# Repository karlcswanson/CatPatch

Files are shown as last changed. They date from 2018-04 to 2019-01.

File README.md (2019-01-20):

# CatPatch
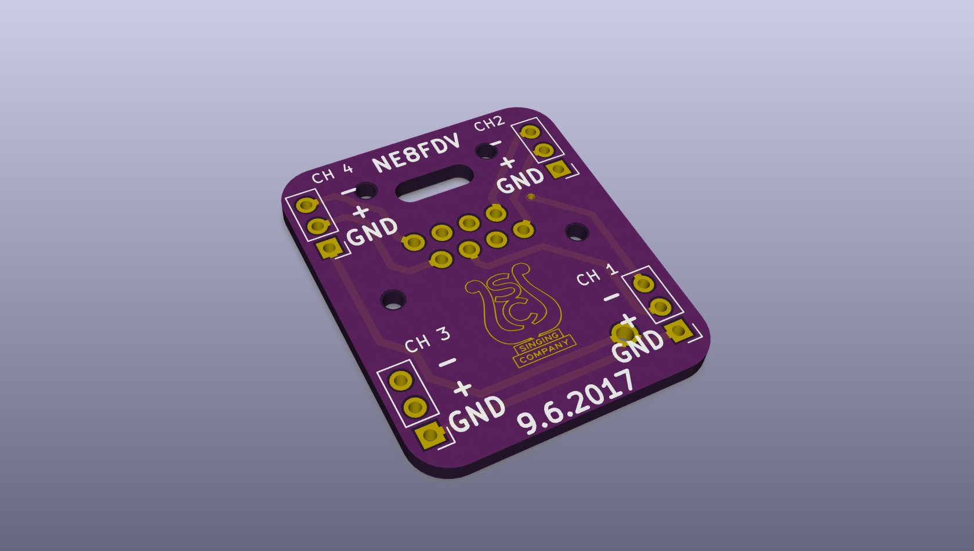
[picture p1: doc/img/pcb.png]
PCB


This repository contains images and KiCad files for a CAT5e subsnake and DI system.

A brief build log for the DI and breakout cable can be found [here](https://imgur.com/a/OviKR).

## Pinouts
The system, as labeled, is pin-compatible with RAT and ETS audio twisted pair products.  The silkscreen and wiring can be adjusted to make it compatible with other standards.

| RJ45 Pin | [T568B](https://en.wikipedia.org/wiki/TIA/EIA-568#Wiring) | RAT & ETS | Radial & Whirlwind |
|:---:|:---:|:---:|:---:|
| 1 | WO | 2+ | 1+ |
| 2 | O | 2- | 1- |
| 3 | WG | 3+ | 2+ |
| 4 | B | 1- | 3+ |
| 5 | WB | 1+ | 3- |
| 6 | G | 3- | 2- |
| 7 | WBr | 4+ | 4+ |
| 8 | Br | 4- | 4- |
---
###### Sources
[RAT CAT Snake](http://www.ratsoundsales.com/mm5/pdf/etherCON_wiring_diagram.pdf) | [Radial Catapult](http://www.radialeng.com/wp-content/uploads/2018/05/Catapult-userguide.pdf) | [Whirlwind Catdusa](http://whirlwindusa.com/media/uploads/catdusa_manual.pdf)

## Cable
Shielded cable is needed when using phantom powered, Clear-Com, and DMX devices over twisted pair.  These devices require pin 1/ground to work. An EtherCON connector does not indicate that a cable is shielded.

Dynamic mics and passive DIs may work without the recommended shield.

## DI
The DI PCB supports the Jensen JT-DB-EPC transformer found in DIs like the Radial JDI. A more affordable transformer can be substituted and can be found in the BOM.

The simplest configuration of the board requires a transformer and 6k81Ω resistor. A stereo summing circuit can be added with a few resistors.  See the [schematic](doc/TSCSnakeDI.pdf) and the [classic RaneNote](https://www.rane.com/note109.html) for more details.

A [drill template](doc/drillguide.pdf) can be found in the docs folder.

Labels can be printed on standard ID cards and can be attached with 3M Command Strip adhesive.
##### Frequency Response

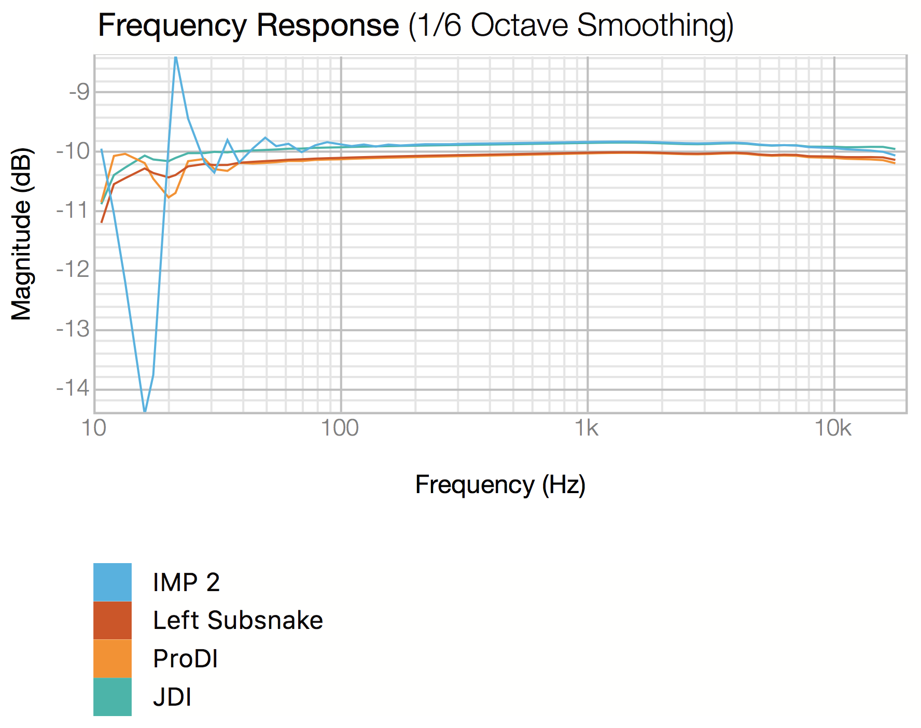
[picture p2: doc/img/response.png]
Response

## I just want the boards, how do I get boards?
The boards used for this project are shared at [OSHPARK](https://oshpark.com/profiles/karlcswanson) and can be ordered there.

## BOM
#### Breakout Panel

| Item | Manufacturer | Quantity | Price Each |
|:---|:---|:---:|---:|
| [CH1/10 1U rackmount chassis][1] | Redco | 1 | $66.95 |
| [NE8FDV-B Vertical EtherCON][2] | Neutrik | 7 | $4.17 |
| [NC3MXX-BAG Male XLR][3] | Neutrik | 28 | $2.96 |
| [SBR Rubber Push-In Grommet 1-3/16" ID][4] | - | 1 |  $11.80/10 |
| [Neutrik Black Screw for etherCon][5] | Neutrik | 14 | $.21 |
| [Neutrik DBA-BL D blank][6] | Neutrik | 1 | $.73 |
| [Flat Head Screws][7] | - | 2 | $6.49/50 |
| [Steel Locknut with Lock Washer][8] | - | 2 |  $8.72/100 |
| N8FDV breakout PCB | Custom | 7 | - |

#### DI Box
| Item | Manufacturer | Quantity | Price Each |
|:---|:---|:---:|---:|
| [Steel Project Box Pre-Punched for 5 D Series XLRs][11] | Pro Speaker Parts | 1 | $16.65 |
| [NE8FDV-B Vertical EtherCON][2] | Neutrik | 1 | $4.17 |
| [NC3FD-L-1-BAG Panel mount D XLR][12] | Neutirk | 2 | $3.22 |
| [NJ3FP6C-BAG Panel mount D TRS][13] | Neutrik | 2 | $5.76 |
| [JT-DB-EPC Transformer][14] | Jensen |  1 - 2 | $73.08 |
| __OR__ | | | |
| [Transformer for PROAV2 and PRODI][15] | Radial |  1 - 2 | $36.00 |
| [Neutrik Black Screw for etherCon][5] | Neutrik | 2 | $.21 |
| [Flat Head Screws][7] | - | 8 | $6.49/50 |
| [Steel Locknut with Lock Washer][8] | - | 8 |  $8.72/100 |
| [Press-Fit Threaded Standoffs][16] | - | 4 | $9.14/25 |
| [Button Head Hex Drive Screw][17] | - | 4 | $11.00/100 |
| N8FDV breakout PCB | Custom | 1 | - |
| DI breakout PCB | Custom | 1 | - |

[1]: https://www.redco.com/Redco-CH1-10-10-Deep-1U-Rackmount-Chassis.html
[2]: http://www.fullcompass.com/prod/516653-Neutrik-NE8FDV-B
[3]: https://www.redco.com/Neutrik-NC3MXX-BAG.html
[4]: https://www.mcmaster.com/#9600k119/=1cjo0vf
[5]: http://www.fullcompass.com/prod/199358-Neutrik-E-SCREW1-12B
[6]: http://www.neutrik.com/en/xlr/xlr-chassis-connectors-accessories/dba-bl
[7]: https://www.mcmaster.com/#91698a306/=1cjoepo
[8]: https://www.mcmaster.com/#93825a110/=1cjog5u

[11]: https://www.ebay.com/itm/Steel-Project-Box-4-1-2-x-3-3-4-x-1-5-8-Pre-Punched-for-5-D-Series-XLRs/281422391821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
[12]: https://www.redco.com/Neutrik-NC3FD-L-1-BAG.html
[13]: https://www.redco.com/Neutrik-NJ3FP6C-BAG.html
[14]: http://www.jensen-transformers.com/transformers/direct-box/
[15]: http://www.fullcompass.com/prod/279709-Radial-Engineering-R800-9033-00
[16]: https://www.mcmaster.com/#93090a210/=1cjopy9
[17]: https://www.mcmaster.com/#91255a106/=1cjoqt3

## Project Images
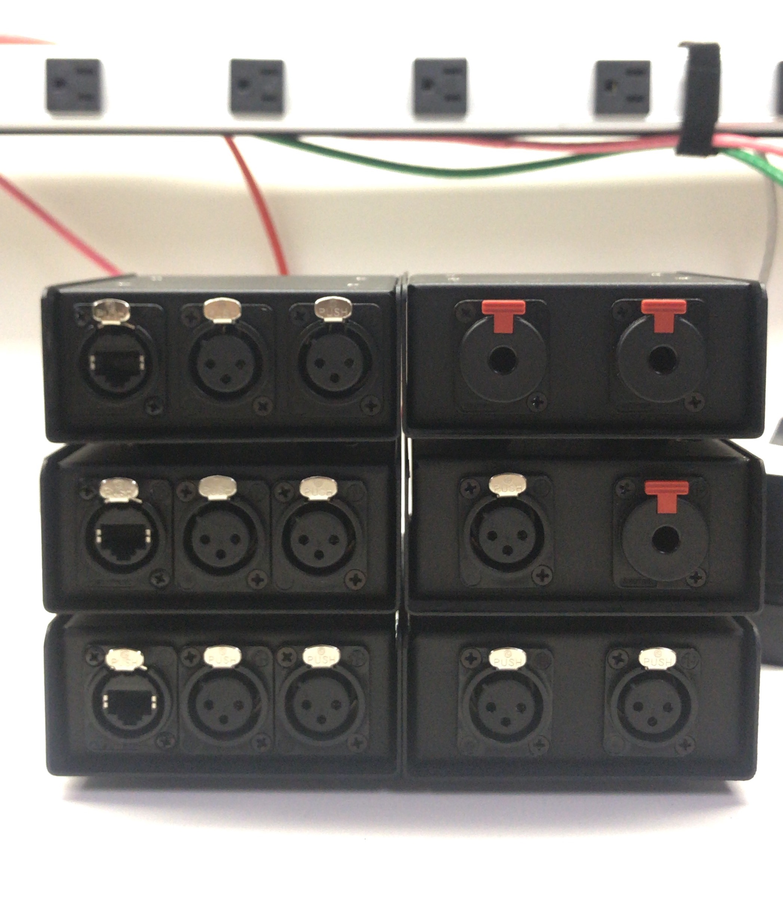
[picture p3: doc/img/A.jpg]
completed boxes

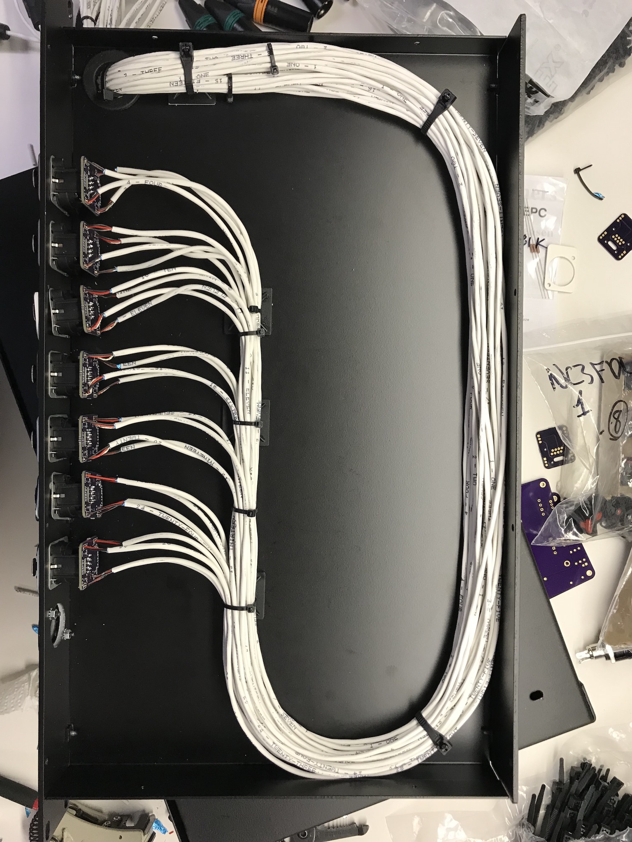
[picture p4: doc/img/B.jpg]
rack wiring

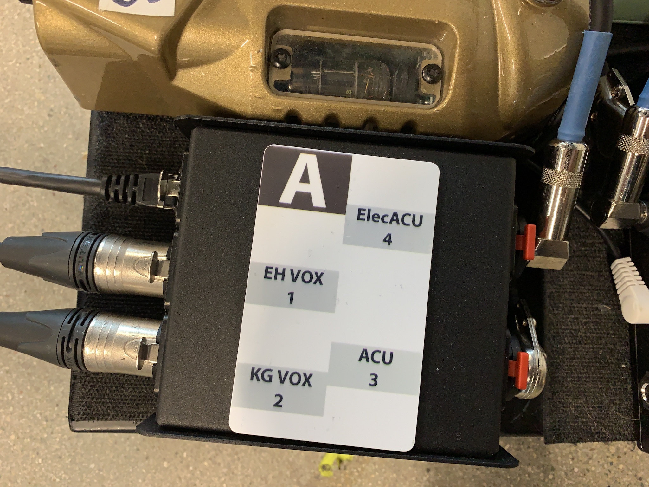
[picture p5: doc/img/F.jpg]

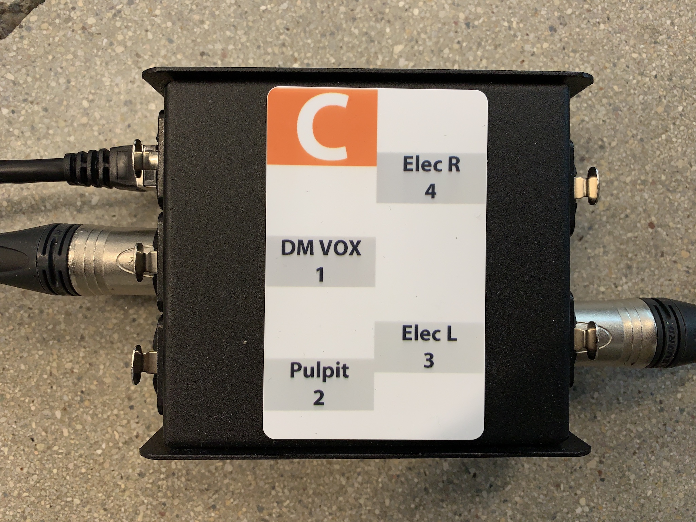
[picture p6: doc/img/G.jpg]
Elec

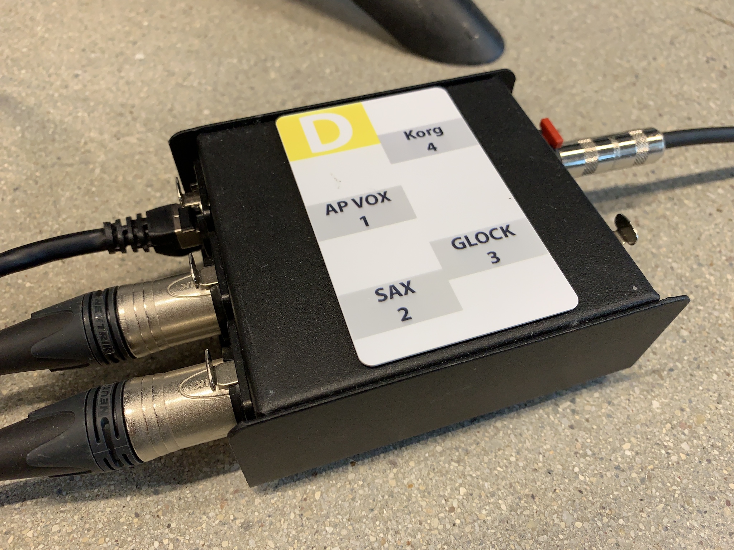
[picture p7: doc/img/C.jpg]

Rack

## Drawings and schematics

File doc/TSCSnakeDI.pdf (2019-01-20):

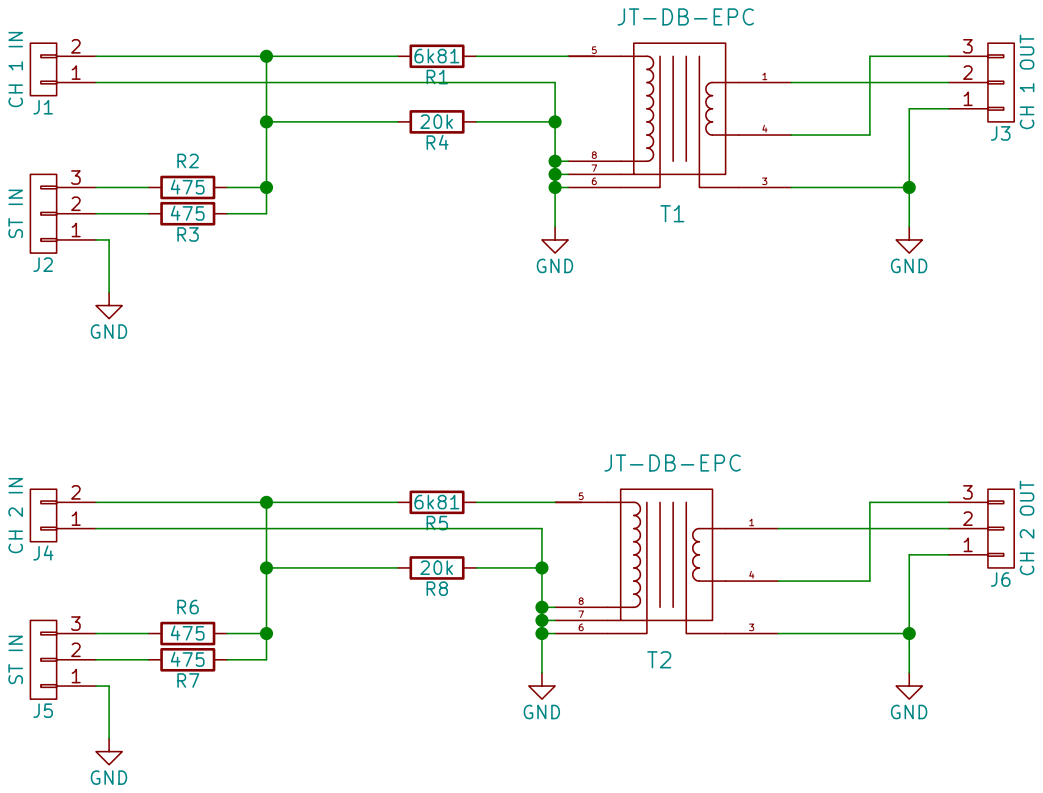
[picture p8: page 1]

Id: 1/1 Title: File: TSCSnakeDI.sch Sheet: /

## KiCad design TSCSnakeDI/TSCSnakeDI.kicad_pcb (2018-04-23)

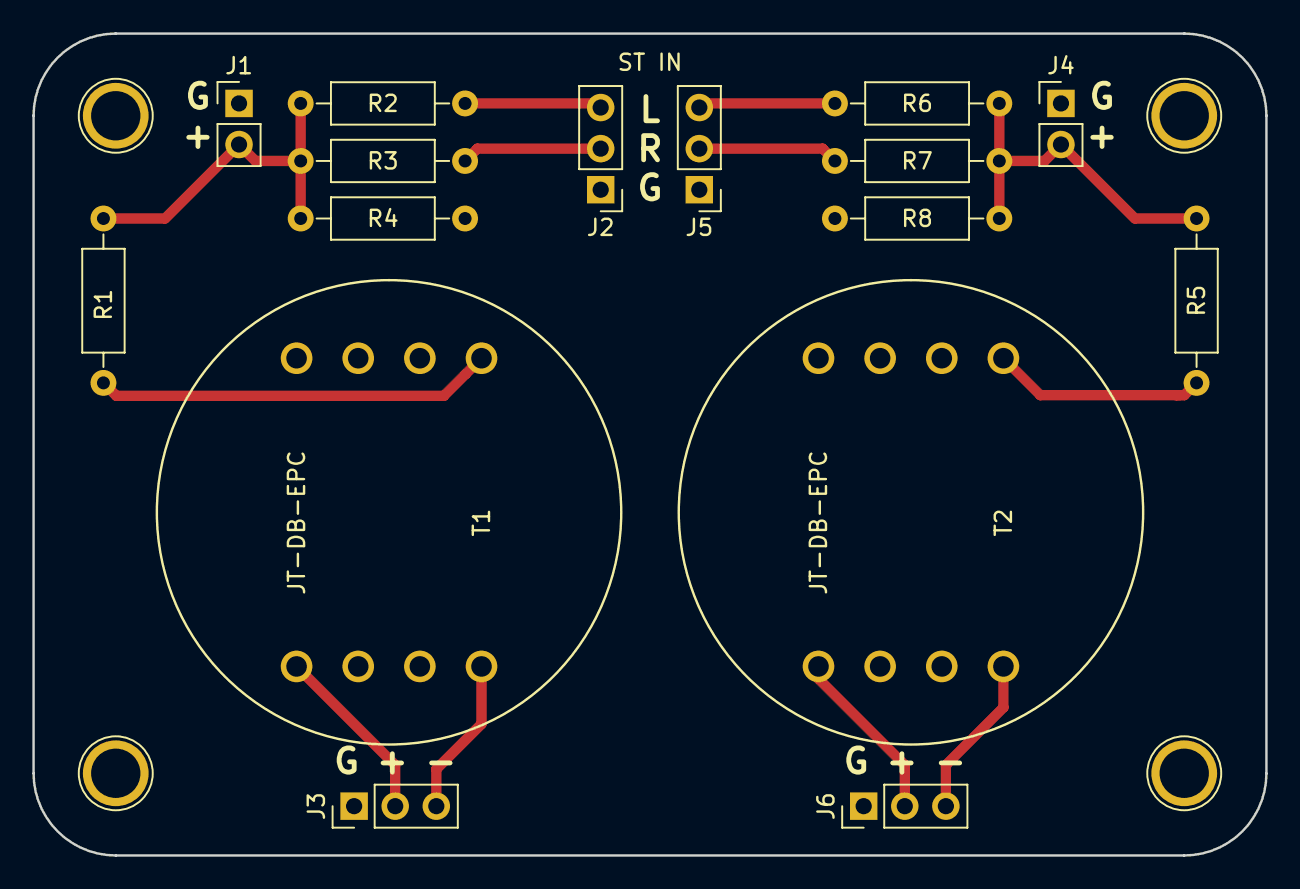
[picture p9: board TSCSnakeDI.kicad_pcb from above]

Board: 2 copper layers, 76.2 x 50.8 mm, 16 parts (0 on the bottom side), 13 nets.

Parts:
J1: CH 1 IN; Pin_Header_Straight_1x02_Pitch2.54mm
J2, J5: ST IN; Pin_Header_Straight_1x03_Pitch2.54mm
J3: CH 1 OUT; Pin_Header_Straight_1x03_Pitch2.54mm
J4: CH 2 IN; Pin_Header_Straight_1x02_Pitch2.54mm
J6: CH 2 OUT; Pin_Header_Straight_1x03_Pitch2.54mm
R1, R5: 6k81; R_Axial_DIN0207_L6.3mm_D2.5mm_P10.16mm_Horizontal
R2, R3, R6, R7: 475; R_Axial_DIN0207_L6.3mm_D2.5mm_P10.16mm_Horizontal
R4, R8: 20k; R_Axial_DIN0207_L6.3mm_D2.5mm_P10.16mm_Horizontal
T1, T2: JT-DB-EPC

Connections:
GND: J1.1, J2.1, J3.1, J4.1, J5.1, J6.1, R4.1, R8.1, T1.3, T1.6, T1.7, T1.8, T2.3, T2.6, T2.7, T2.8
unnamed: J1.2, R1.2, R2.1, R3.1, R4.2
unnamed: J2.2, R3.2
unnamed: J2.3, R2.2
unnamed: J3.2, T1.1
unnamed: J3.3, T1.4
unnamed: J4.2, R5.2, R6.1, R7.1, R8.2
unnamed: J5.2, R7.2
unnamed: J5.3, R6.2
unnamed: J6.2, T2.1
unnamed: J6.3, T2.4
unnamed: R1.1, T1.5
unnamed: R5.1, T2.5

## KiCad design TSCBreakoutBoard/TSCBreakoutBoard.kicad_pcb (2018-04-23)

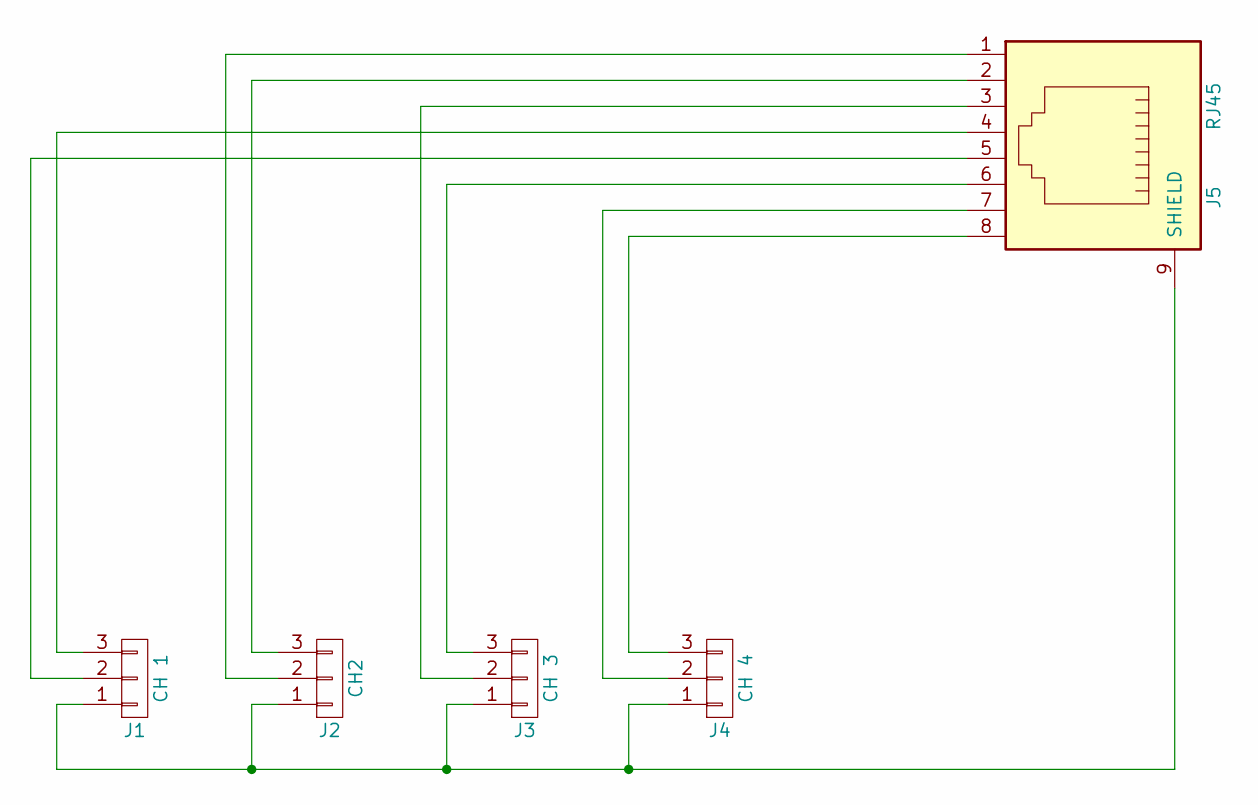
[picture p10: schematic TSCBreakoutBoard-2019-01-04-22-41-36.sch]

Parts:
J1: CH 1; Pin_Header_Straight_1x03_Pitch2.54mm
J2: CH2; Pin_Header_Straight_1x03_Pitch2.54mm
J3: CH 3; Pin_Header_Straight_1x03_Pitch2.54mm
J4: CH 4; Pin_Header_Straight_1x03_Pitch2.54mm
J5: RJ45; NE8FDV

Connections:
unnamed: J1.1, J2.1, J3.1, J4.1, J5.9 (SHIELD)
unnamed: J1.2, J5.5
unnamed: J1.3, J5.4
unnamed: J2.2, J5.1
unnamed: J2.3, J5.2
unnamed: J3.2, J5.3
unnamed: J3.3, J5.6
unnamed: J4.2, J5.7
unnamed: J4.3, J5.8

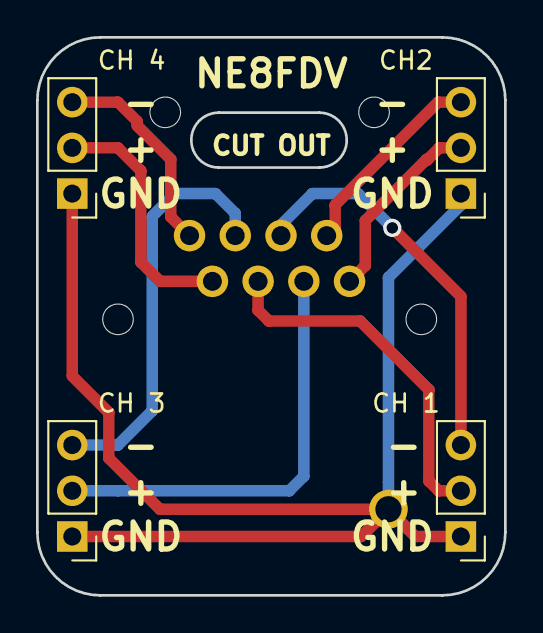
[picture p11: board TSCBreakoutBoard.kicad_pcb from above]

Board: 2 copper layers, 26.0 x 31.0 mm, 5 parts (0 on the bottom side), 9 nets.

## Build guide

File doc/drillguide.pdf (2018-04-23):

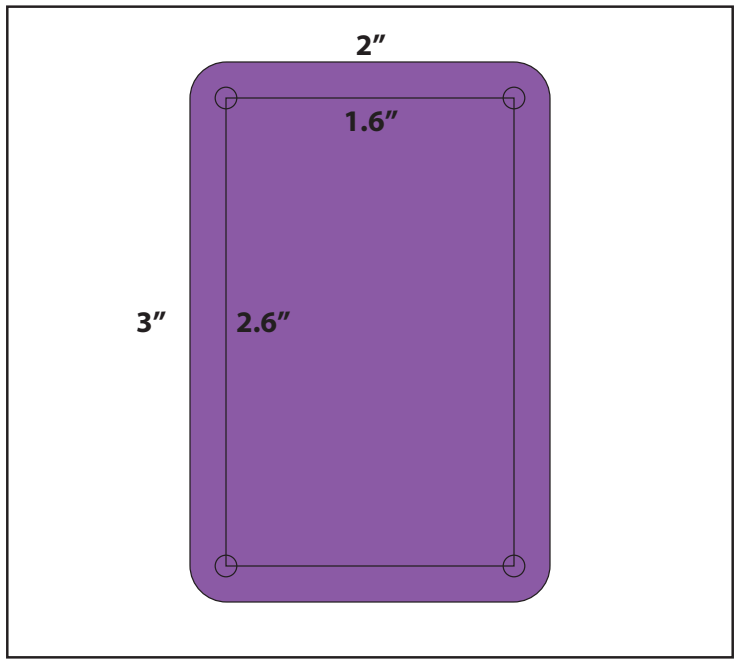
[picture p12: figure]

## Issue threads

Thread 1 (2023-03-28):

License?

konkers, 2023-03-28:
Hi, I found this project while looking for a NE8FDV kicad footprint.  I'd love to use yours for my project but don't see any license terms stated for this project.  Would be great if you could add one!

karlcswanson, 2023-03-29:
Thanks for checking! I think I looked into adding in a license earlier but couldn't figure out the best route to take on the hardware side of things with monorepo that contains a project & libraries.

Just licensed as MIT. Hope that works for you (and KiCad).

Closed 2023-03-29.

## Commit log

2018-04-18 Initial Commit
    Initial Commit!
    [TSC Snake.dsn, TSC Snake.kicad_pcb, TSC Snake.sch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]
2018-04-23 remove logo & date
    [TSCBreakoutBoard.kicad_pcb]
2018-04-23 remove logo, relative paths
    [TSCBreakoutBoard.kicad_pcb]
2018-04-23 remove logo & old breakout PCB
    [TSC Snake.dsn, TSC Snake.kicad_pcb, TSC Snake.sch]
2018-04-23 Remove logo & link DI PCB
    [TSCSnakeDI.kicad_pcb]
2018-04-23 Add drill guide
2018-04-24 Update BOM
